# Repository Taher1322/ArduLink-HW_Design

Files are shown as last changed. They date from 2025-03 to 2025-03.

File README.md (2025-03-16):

ArduLink Shield is a platform that brings many Arduino projects to life quickly without having to do a lot of breadboard connections.

</br>

ArduLink enables a modular plug and play approach for enthusiast to design and develop applications as suits their end goal. It is a tool that provides the ability to develop applications faster without worrying about hardware components.

</br>

This repository includes all the design files - schematics and layout

</br>

General Block Diagram

</br>

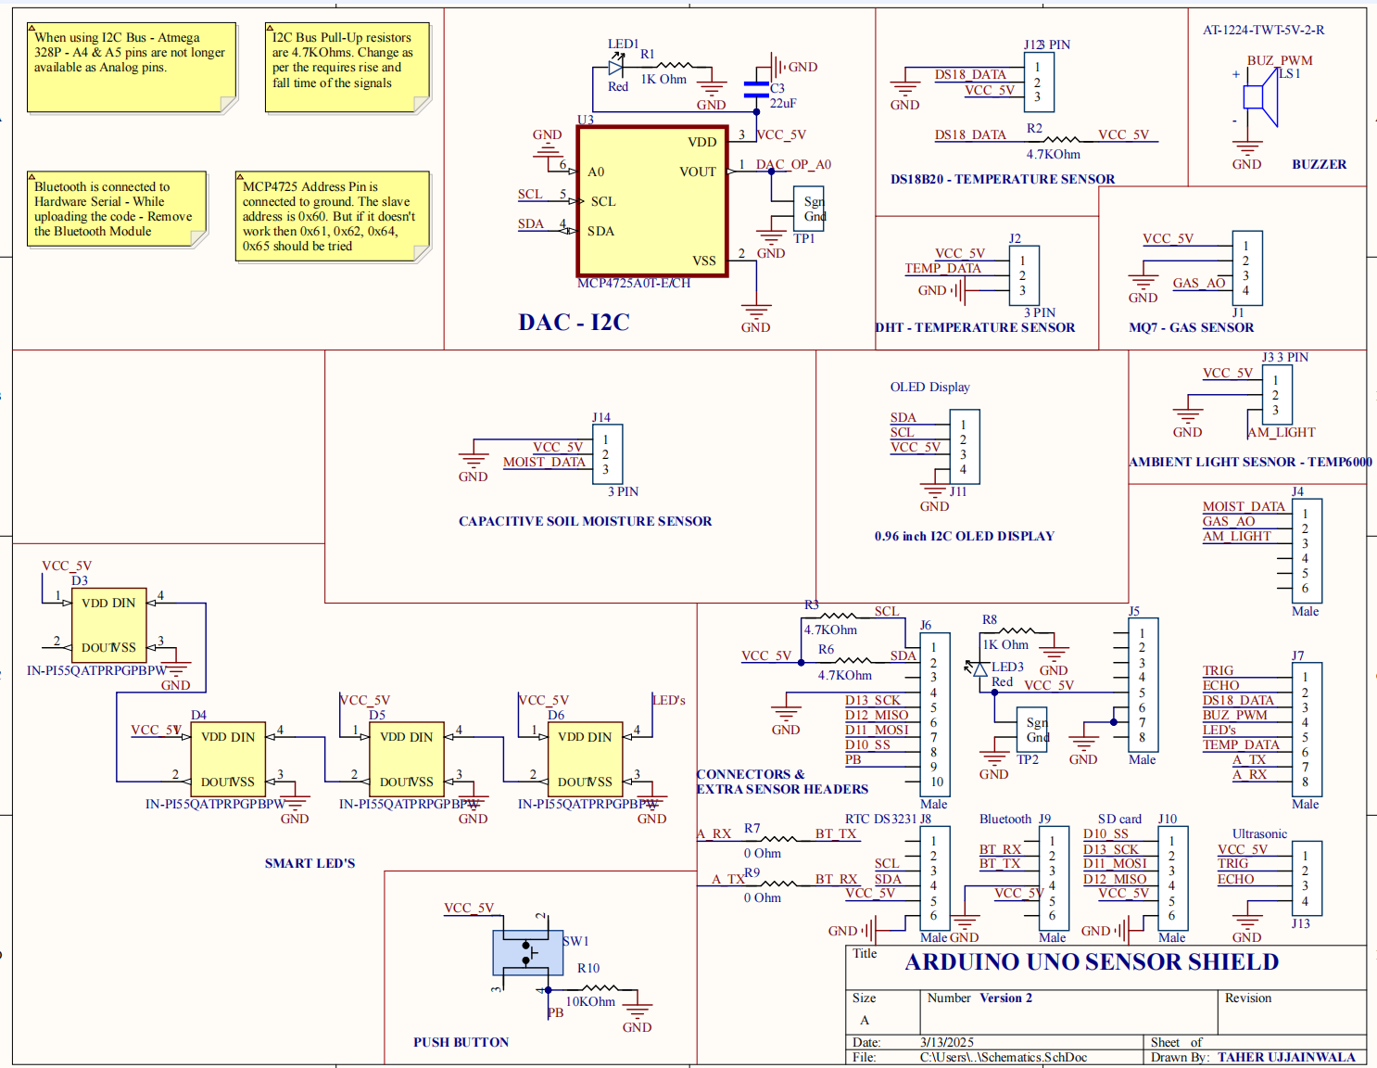
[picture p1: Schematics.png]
Schematics


ArduLink Shield

# Pin Mapping

| Arduino Uno/Mega  | ArduLink Shield |
| --- | --- |
| Analog Pin A0 | Moisture Sensor  |
| Analog Pin A1  | Gas Sensor MQ7  |
| Analog Pin A2 |  Ambient Light TEMT600 Sensor|
| Analog Pin A3 |  Future Expansion |
| Analog Pin A4 | I2C SDA - DAC, RTC & OLED Display |
| Analog Pin A5 | I2C SCL - DAC, RTC & OLED Display |
| Digital Pin 0 - Arduino RX | Bluetooth HC-05 TX |
| Digital Pin 1 - Arduino TX | Bluetooth HC-05 RX |
| Digital Pin 2 | Temperature and Humidity DHT11/22 Sensor |
| Digital Pin 3 | Smart NeoPixel LED's |
| Digital Pin 4 | Buzzer |
| Digital Pin 5 | Temperature DS18B20 Sensor |
| Digital Pin 6 | Ultrasonic Sensor Echo Pin |
| Digital Pin 7 | Ultrasonic Sensor Trigger Pin |
| Digital Pin 8 | Future Expansion |
| Digital Pin 9 | Push Button |
| Digital Pin 10 | SD Card Chip Select Pin |
| Digital Pin 11 | SD Card MOSI Pin |
| Digital Pin 12 | SD Card MISO Pin |
| Digital Pin 13 | SD Card SCK Pin |

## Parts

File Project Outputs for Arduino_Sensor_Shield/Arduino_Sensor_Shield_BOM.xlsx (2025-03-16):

Comment | Description | Designator | Footprint | LibRef | Quantity | LCSC Part#
22uF | 22µF ±20% 16V Ceramic Capacitor X5R 1206 (3216 Metric) | C3 | 1206_Passive_Capacitor | C_22uF_1206 | 1 | C12891
1uF | 1µF ±20% 16V Ceramic Capacitor X7R 1206 (3216 Metric) | C4 | 1206_Passive_Capacitor | C_1uF_1206 | 1 | C1848
IN-PI55QATPRPGPBPW | Digital Series Cascade LED | D3, D4, D5, D6 | SERIAL_LED | LED_Smart_5050 | 4 | [NoParam], C2843785
J_4_PIN_HEADER | 4 Position Header Connector 0.100" (2.54mm) Through Hole Tin | J1, J11, J13 | 4_PIN_100MIL | J_4_PIN_HEADER | 3
3 PIN | 3 2.54mm Straight 1 Header，Breakaway Through Hole Pin Header & Female Header ROHS | J2, J3, J12, J14 | 3_PIN_100mil | J_3_PIN_HEADER | 4 | C49257
PPTC061LFBN-RC | 6 Position Header Connector 0.100" (2.54mm) Through Hole Tin | J4, J8, J9, J10 | 6_PIN_ARDUINO_100mil | JM_6_PIN_MALE_ARDUINO | 4 | DNP
PPTC081LFBN-RC | 8 Position Header Connector 0.100" (2.54mm) Through Hole Tin | J5, J7 | 8_PIN_ARDUINO_100MIL | JM_8_PIN_MALE_ARDUINO | 2 | DNP
PPTC101LFBN-RC | 10 Position Header Connector 0.100" (2.54mm) Through Hole Tin | J6 | 10_PIN_ARDUINO_100MIL | JM_10_PIN_MALE_ARDUINO | 1 | DNP
LTST-C150CKT | Red 638nm LED Indication - Discrete 1.8V 1206 (3216 Metric) | LED1, LED3 | LED | LED_1206 | 2 | C93133
AT-1224-TWT-5V-2-R | AUDIO TRANSDUCER 5 VP-P 87 DB 2400 HZ | LS1 | XDCR_AT-1224-TWT-5V-2-R | AT-1224-TWT-5V-2-R | 1 | C417411
CMEJ-0415-42-P | 4.0 Ð¼Ð¼, Ð²Ñ ÐµÐ½Ð°Ð¿Ñ€Ð°Ð²Ð»ÐµÐ½Ð½Ñ‹Ð¹, Ð¼Ð¾Ð½Ñ‚Ð°Ð¶ Ð½Ð° Ð¿ÐµÑ‡Ð°Ñ‚Ð½Ð¾Ð¹ Ð¿Ð»Ð°Ñ‚Ðµ, 2.0 Ð’ Ð¿Ð¾Ñ Ñ‚Ð¾Ñ Ð½Ð½Ð¾Ð³Ð¾ Ñ‚Ð¾ÐºÐ°, ÐÐ»ÐµÐºÑ€ÐµÑ‚-ÐºÐ¾Ð½Ð´ÐµÐ½Ñ Ð°Ñ‚Ð¾Ñ€Ð½Ñ‹Ð¹ Ð¼Ð¸ÐºÑ€Ð¾Ñ„Ð¾Ð½ | MK1 | MIC_CMEJ-0415-42-P | CMEJ-0415-42-P | 1 | C3273725
1k | 1 kOhms ±1% 0.5W, 1/2W Chip Resistor 1206 (3216 Metric) Anti-Sulfur, Moisture Resistant Thin Film | R1, R4, R5, R8 | 1206_Passive_Resitor | R_1K_1206 | 4 | C4410
4.7KOhm | 4.7kΩ ±1% 0.25W ±100ppm/℃ 1206 Chip Resistor - Surface Mount RoHS | R2, R3, R6 | 1206_Passive_Resitor | R_4.7k_1206 | 3 | C17936
0 Ohm | CHIP RESISTOR - SURFACE MOUNT 0OHMS ±1% 1/16W 0402 ROHS | R7, R9 | 0402_Passive_Resistor | R_0Ohm_0402 | 2 | C17168
10k | 10 kOhms ±5% 0.25W, 1/4W Chip Resistor 1206 (3216 Metric) Automotive AEC-Q200 Thick Film | R10 | 1206_Passive_Resitor | R_10KOhm_1206 | 1 | C17902
TL3305AF160QG | Tactile Switch SPST-NO Top Actuated Surface Mount | SW1 | Switch_JLC | SW_Push_Button_JLC | 1 | C174049
10x Probe TP | Test Point 300 mil centers | TP1, TP2 | TP10x_Probe | TP_10x_Probe | 2
MCP4725A0T-E/CH | 12 Bit Digital to Analog Converter 1 SOT-23-6 | U3 | SOT95P270X145-6N | MCP4725A0T-E/CH | 1 | C144198

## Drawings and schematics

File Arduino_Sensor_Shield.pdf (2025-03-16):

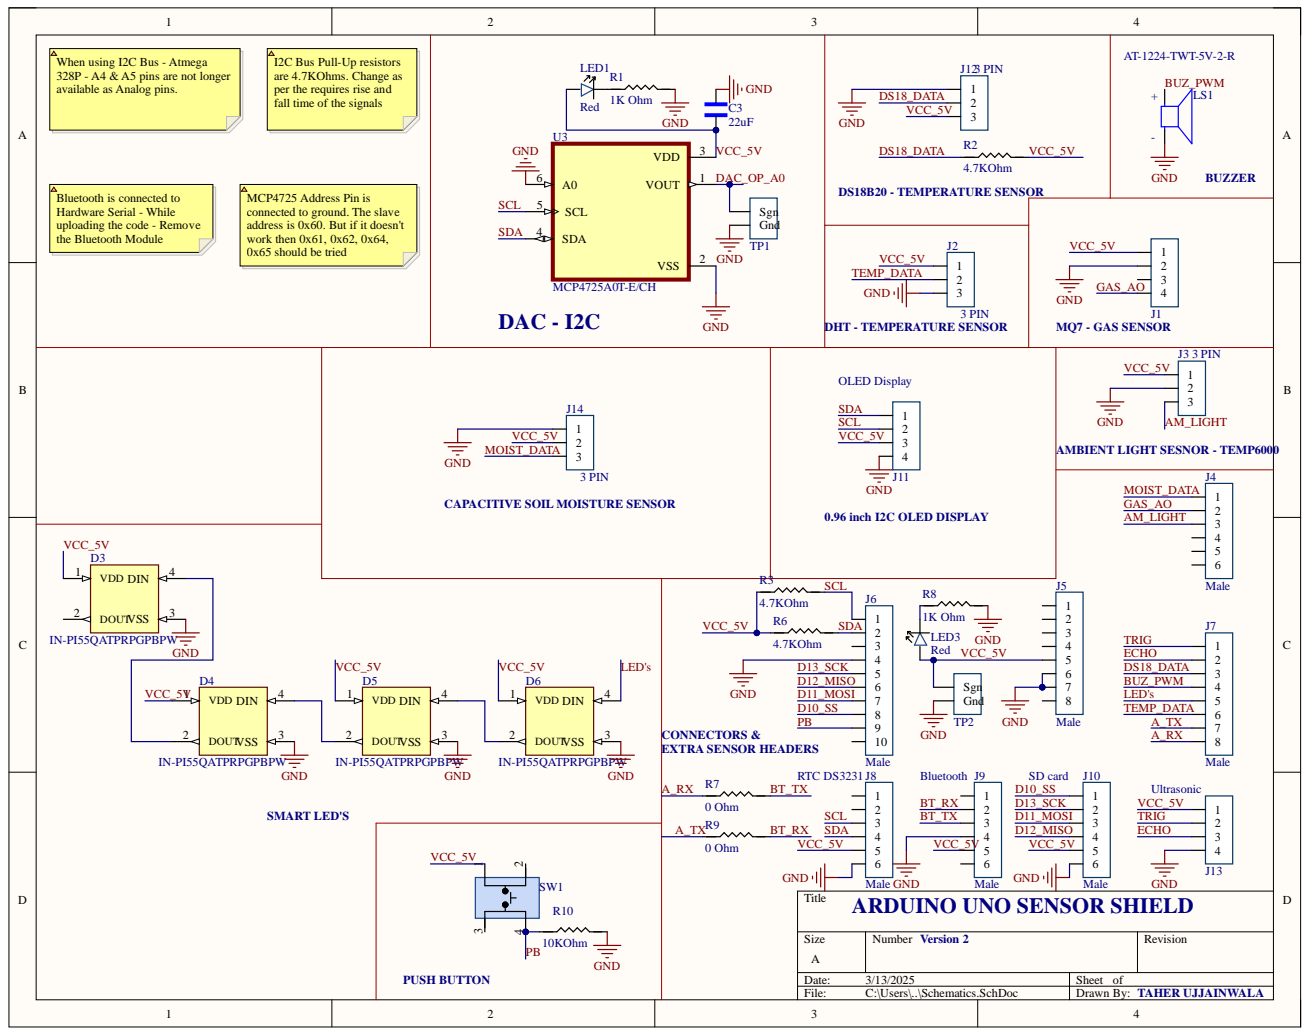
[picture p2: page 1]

When using I2C Bus - Atmega
328P - A4 & A5 pins are not longer
available as Analog pins.

I2C Bus Pull-Up resistors
are 4.7KOhms. Change as
per the requires rise and
fall time of the signals

Bluetooth is connected to
Hardware Serial - While
uploading the code - Remove
the Bluetooth Module

MCP4725 Address Pin is
connected to ground. The slave
address is 0x60. But if it doesn't
work then 0x61, 0x62, 0x64,
0x65 should be tried

CAPACITIVE SOIL MOISTURE SENSOR

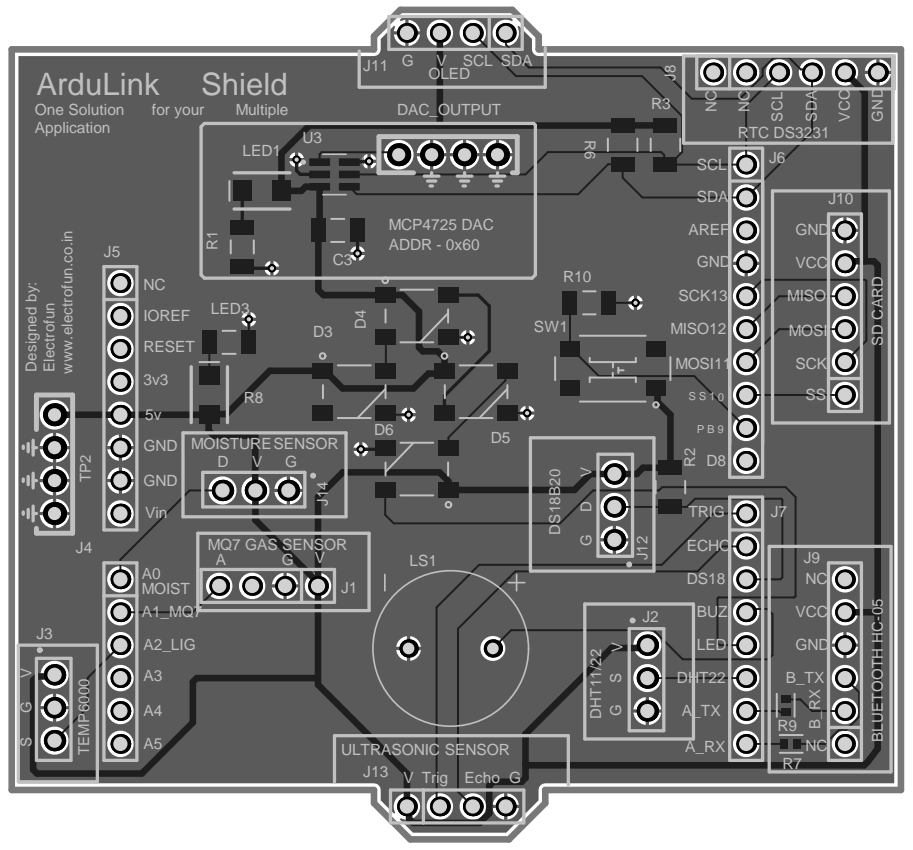
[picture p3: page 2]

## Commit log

2025-03-16 design files
    [Arduino_Sensor_Shield.PrjPcb, Arduino_Sensor_Shield_BOM.xlsx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]
2025-03-16 schematics added
